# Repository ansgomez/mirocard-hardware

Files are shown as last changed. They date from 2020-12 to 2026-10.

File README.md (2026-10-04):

# MiroCard Hardware Files

Hardware design files for the MiroCard, a batteryless, light-powered BLE smart card
(TI CC2650 MCU, e-peas AEM10941 harvester, Epishine organic solar cell).

The current version, `MiroCard_V2.0/`, contains:

* `Datasheet_MiroCard_V2.pdf` – datasheet
* `Schematics_MiroCard_V2.pdf` – schematics
* `Altium_Files_MiroCard_V2/` – Altium project for the PCB design and production
  (schematics, PCB, libraries, Gerber/drill/pick-and-place outputs, BOM and STEP model)

Contact: [Andres Gomez](https://andresgomez.ch).

## Contributors

* Sinan Uyan (PCB layout)
* Andres Gomez

## MiroCard project

Project website: <https://ansgomez.github.io/mirocard-website/>

The MiroCard is a batteryless, light-powered BLE smart card, designed by Andres Gomez
(Miromico AG) and inspired by the
[Transient BLE Node](https://gitlab.ethz.ch/tec/public/employees/sigristl/transient_ble_node)
project developed at ETH Zurich. It was presented in:

> Andres Gomez. 2020. *Demo Abstract: On-Demand Communication with the Batteryless MiroCard.*
> In The 18th ACM Conference on Embedded Networked Sensor Systems (SenSys '20).
> [doi:10.1145/3384419.3430440](https://doi.org/10.1145/3384419.3430440)

Related repositories:

| Repository | Contents |
| --- | --- |
| **mirocard-hardware** (this repository) | Hardware: datasheet, schematics and Altium PCB project (MiroCard V2.0) |
| [mirocard-contiki-ng](https://github.com/ansgomez/mirocard-contiki-ng) | Firmware: Contiki-NG fork with the MiroCard platform and example applications |
| [miroreader-app](https://github.com/ansgomez/miroreader-app) | Android app to receive and display MiroCard beacons |
| [mirocard-scanner-python](https://github.com/ansgomez/mirocard-scanner-python) | Python scripts to scan for and decode MiroCard beacons (bluepy) and discover devices (gattlib) |
| [mirocard-scanner-mqtt](https://github.com/ansgomez/mirocard-scanner-mqtt) | Node.js bridge forwarding MiroCard beacons to an MQTT broker |
| [mirocard-scanner-influx](https://github.com/ansgomez/mirocard-scanner-influx) | Node.js bridge storing MiroCard beacons in InfluxDB |
| [mirocard-webid](https://github.com/ansgomez/mirocard-webid) | Web Bluetooth demo page for identification and sensor readout |
| [mirocard-postprocessing](https://github.com/ansgomez/mirocard-postprocessing) | Jupyter notebook to post-process RocketLogger power measurements |
| [mirocard-plotly](https://github.com/ansgomez/mirocard-plotly) | Plotly Dash web app visualizing a RocketLogger measurement |

## Copyright and License

The MiroCard and MiroReader app are designed by Andres Gomez, inspired by the
[Transient BLE Node](https://gitlab.ethz.ch/tec/public/employees/sigristl/transient_ble_node)
project developed at ETH Zurich. The Transient BLE Node project is released under the
Creative Commons Attribution 4.0 International License (CC BY 4.0); the Altium libraries
`MiroCard/TransientBLE.SCHLIB` and `MiroCard/TransientBLE.PcbLib` originate from that project.

The MiroCard hardware files are released under the BSD 3-Clause License, see [LICENSE](LICENSE).

Copyright: (c) 2020, Andres Gomez, Miromico AG

Copyright: (c) 2017-2020, ETH Zurich, Computer Engineering Group and Microelectronics Design Center.

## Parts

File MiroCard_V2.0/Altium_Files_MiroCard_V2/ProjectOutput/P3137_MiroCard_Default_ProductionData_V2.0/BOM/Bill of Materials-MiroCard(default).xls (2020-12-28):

 | Part List |  |  |  | P3137001-02
 | Project Number: |  |  |  | P3137 |  |  | Author Miromico: | AG
 | Project: |  |  |  | MiroCard.PrjPcb |  |  | Quantity: | 0 | Total quantity = Quantity + Prototypes
 | Variant: |  |  |  | default |  |  | Prototypes: | 1
 | Revision: |  |  |  | 2.0
 | Report Date: |  |  | 16.12.2020 | 14:37
 |  |  |  |  |  |  |  |  |  |  |  |  |  |  |  | Pricing
Pos. | PartType | Designator | Quantity | Needed Qty | Footprint | Description | Properties | Comment | Manufacturer | Manufacturer Part Number | Supplier 1 | Supplier Part Number 1 | #Column Name Error:' Supplier 2 | #Column Name Error:' Supplier Part Number 2 | Replaceable (with) | Supplier Currency 1 | Supplier Unit Price 1 | Supplier Subtotal 1 | #Column Name Error:' Supplier Currency 2 | #Column Name Error:' Supplier Unit Price 2 | #Column Name Error:' Supplier Subtotal 2
 | GRM155R61C104KA88D | C100, C101, C102, C103, C106, C107, C115, C118, C206, C401 | 10 | 10 | CAPC0402(1005)60_L | 0.1µF ±10% 16V Ceramic Capacitor X5R 0402 (1005 Metric) |  | GRM155R61C104KA88D | Murata Electronics | GRM155R61C104KA88D | Digi-Key | 490-5415-1-ND
 | GRJ155R60J106ME11D | C104, C105, C300, C301, C302, C303, C304, C406 | 8 | 8 | CAPC0402(1005)60_L | 10µF ±20% 6.3V Ceramic Capacitor X5R 0402 (1005 Metric) |  | GRJ155R60J106ME11D | Murata Electronics | GRJ155R60J106ME11D | Digi-Key | 490-13211-1-ND
 | CAP 6.8pF 10V 0402(1005) | C108 | 1 | 1 | CAPC0402(1005)60_L | CAP 6.8pF 10V ±5% 0402 (1005 Metric) Thickness 0.6mm SMD |  | CAP 6.8pF 10V 0402(1005)
 | GRM1555C1H1R0BA01D | C109, C112, C113 | 3 | 3 | CAPC0402(1005)60_L | 1pF ±0.1pF 50V Ceramic Capacitor C0G, NP0 0402 (1005 Metric) |  | GRM1555C1H1R0BA01D | Murata Electronics | GRM1555C1H1R0BA01D | Digi-Key | 490-6206-1-ND
 | CAP 12pF 10V 0402(1005) | C110 | 1 | 1 | CAPC0402(1005)60_L | CAP 12pF 10V ±2% 0402 (1005 Metric) Thickness 0.6mm SMD |  | CAP 12pF 10V 0402(1005)
 | GRM1555C1H1R8BA01D | C111 | 1 | 1 | CAPC0402(1005)60_L | 1.8pF ±0.1pF 50V Ceramic Capacitor C0G, NP0 0402 (1005 Metric) |  | GRM1555C1H1R8BA01D | Murata Electronics | GRM1555C1H1R8BA01D | Digi-Key | 490-6215-1-ND
 | GRM155R70J105KA12J | C114, C207 | 2 | 2 | CAPC0402(1005)60_L | 1µF ±10% 6.3V Ceramic Capacitor X7R 0402 (1005 Metric) |  | GRM155R70J105KA12J | Murata Electronics | GRM155R70J105KA12J | Digi-Key | 490-13339-1-ND
 | GRM1555C1H120JA01D | C116, C117 | 2 | 2 | CAPC0402(1005)60_L | 12pF ±5% 50V Ceramic Capacitor C0G, NP0 0402 (1005 Metric) |  | GRM1555C1H120JA01D | Murata Electronics | GRM1555C1H120JA01D | Digi-Key | 490-5924-1-ND
 | CAP 47uF 6.3V 0805(2012) | C204, C205 | 2 | 2 | CAPC0805(2012)95_L | CAP 47uF 6.3V ±20% 0805 (2012 Metric) Thickness 0.95mm SMD |  | CAP 47uF 6.3V 0805(2012)
 | GRM155R71E104KE14J | C400, C405 | 2 | 2 | CAPC0402(1005)60_L | 0.1µF ±10% 25V Ceramic Capacitor X7R 0402 (1005 Metric) |  | GRM155R71E104KE14J | Murata Electronics | GRM155R71E104KE14J | Digi-Key | 490-14603-1-ND
 | APTF1616LSEEZGKQBKC | D100 | 1 | 1 | APTF1616LSEEZGKQBKC | HELI Colour; 1.6X1.6MM LOW CURRENT RGB SMD LED | Red, Green, Blue (RGB) 621nm Red, 525nm Green, 465nm Blue LED Indication - Discrete 1.8V Red, 2.7V Green, 2.7V Blue 0606 (1616 Metric) | APTF1616LSEEZGKQBKC | Kingbright | APTF1616LSEEZGKQBKC | Digi-Key | 754-1972-1-ND
 | BLM18HE152SN1D | FB100 | 1 | 1 | MURA-BLM18-RF-H4-CHIP-2_V | Chip Ferrite Bead for GHz Band High-speed Signal Lines, 1500 Ohm, 500 mA, -55 to 125 degC, 1.6 x 0.8 x 0.95 mm SMD, Tape and Reel |  | BLM18HE152SN1D | Murata
 | CKS2125100M-T | L100, L300 | 2 | 2 | INDC0805(2012)X11_L | FIXED IND 10UH 110MA 520 MOHM |  | CKS2125100M-T
 | LQG15HS2N4S02D | L101, L102, L103, L104 | 4 | 4 | INDC1005X55X25LL05T10_A | Chip Inductor, 2.4 nH, +/- 0.3 nH, 300 mA, -55 to 125 degC, 0402 (1005 Metric), RoHS, Tape and Reel |  | LQG15HS2N4S02D | MurataElectronics
 | MLZ1608M100WT000 | L301 | 1 | 1 | FP-MLZ1608-MFG | FIXED IND 10UH 250MA 1.05 OHM |  | MLZ1608M100WT000 | TDK | MLZ1608M100WT000
 | RMCF0402FT300R | R102, R103, R104 | 3 | 3 | RESC0402(1005)_L | 300 Ohms ±1% 0,063W, 1/16W Chipwiderstand 0402 (1005 metrisch) AutomobilzulassungAEC-Q200 Dickschicht |  | RMCF0402FT300R | Stackpole Electronics Inc | RMCF0402FT300R | Digi-Key | RMCF0402FT300RCT-ND
 | RMCF0402FT100K | R105, R108, R201, R207 | 4 | 4 | RESC0402(1005)_L | 100 kOhms ±1% 0,063W, 1/16W Chipwiderstand 0402 (1005 metrisch) AutomobilzulassungAEC-Q200 Dickschicht |  | RMCF0402FT100K | Stackpole Electronics Inc | RMCF0402FT100K | Digi-Key | RMCF0402FT100KCT-ND
 | RMCF0402FT1M00 | R106, R107 | 2 | 2 | RESC0402(1005)_L | 1 MOhms ±1% 0,063W, 1/16W Chipwiderstand 0402 (1005 metrisch) AutomobilzulassungAEC-Q200 Dickschicht |  | RMCF0402FT1M00 | Stackpole Electronics Inc | RMCF0402FT1M00 | Digi-Key | RMCF0402FT1M00CT-ND
 | PFR05S-153-FNH | R200 | 1 | 1 | RESC0402(1005)_L | 15 kOhms ±1% 0.063W, 1/16W Chip Resistor 0402 (1005 Metric) Thick Film |  | PFR05S-153-FNH | Delta Electronics/Cyntec | PFR05S-153-FNH | Digi-Key | 2037-PFR05S-153-FNHCT-ND
 | CRCW04023M16FKED | R202 | 1 | 1 | RESC0402(1005)_L | 3.16 MOhms ±1% 0.063W, 1/16W Chip Resistor 0402 (1005 Metric) Automotive AEC-Q200 Thick Film |  | CRCW04023M16FKED | Vishay Dale | CRCW04023M16FKED | Digi-Key | 541-3.16MLCT-ND
 | RMCF0603ZT0R00 | R204 | 1 | 1 | RESC0603(1608)_L | 0 Ohms Jumper 0.1W, 1/10W Chip Resistor 0603 (1608 Metric) Automotive AEC-Q200 Thick Film |  | RMCF0603ZT0R00 | Stackpole Electronics Inc | RMCF0603ZT0R00 | Digi-Key | RMCF0603ZT0R00CT-ND
 | RMCF0402FT1M18 | R205 | 1 | 1 | RESC0402(1005)_L | 1.18 MOhms ±1% 0.063W, 1/16W Chip Resistor 0402 (1005 Metric) Automotive AEC-Q200 Thick Film |  | RMCF0402FT1M18 | Stackpole Electronics Inc | RMCF0402FT1M18 | Digi-Key | RMCF0402FT1M18CT-ND
 | RMCF0402FT2M40 | R206 | 1 | 1 | RESC0402(1005)_L | 2.4 MOhms ±1% 0.063W, 1/16W Chip Resistor 0402 (1005 Metric) Automotive AEC-Q200 Thick Film |  | RMCF0402FT2M40 | Stackpole Electronics Inc | RMCF0402FT2M40 | Digi-Key | RMCF0402FT2M40CT-ND
 | RMCF0402ZT0R00 | R301, R307, R309, R311, R312, R318 | 6 | 6 | RESC0402(1005)_L | 0 Ohms Jumper 0.063W, 1/16W Chip Resistor 0402 (1005 Metric) Automotive AEC-Q200 Thick Film |  | RMCF0402ZT0R00 | Stackpole Electronics Inc | RMCF0402ZT0R00 | Digi-Key | RMCF0402ZT0R00CT-ND
 | CRCW04025M49FKED | R303 | 1 | 1 | RESC0402(1005)_L | 5.49 MOhms ±1% 0.063W, 1/16W Chip Resistor 0402 (1005 Metric) Automotive AEC-Q200 Thick Film |  | CRCW04025M49FKED | Vishay Dale | CRCW04025M49FKED | Digi-Key | 541-5.49MLCT-ND
 | CRCW04024M42FKED | R304 | 1 | 1 | RESC0402(1005)_L | 4.42 MOhms ±1% 0.063W, 1/16W Chip Resistor 0402 (1005 Metric) Automotive AEC-Q200 Thick Film |  | CRCW04024M42FKED | Vishay Dale | CRCW04024M42FKED | Digi-Key | 541-4.42MLCT-ND
 | AC0402FR-0710KL | R400, R401, R402, R403, R404 | 5 | 5 | RESC0201(0603)_L | 10 kOhms ±1% 0.063W, 1/16W Chip Resistor 0402 (1005 Metric) Automotive AEC-Q200, Moisture Resistant Thick Film |  | AC0402FR-0710KL | Yageo | AC0402FR-0710KL | Digi-Key | YAG3436CT-ND
 | KMT021NGJLHS | SW100, SW101 | 2 | 2 | KMT021NGJLHS-Footprint-1 | Sensorschalter Ultra-LW Tact SW SMT SPNOFa 1.6N HF |  | KMT021NGJLHS | C&K | KMT021NGJLHS | Mouser | 611-KMT021NGJLHS
 | LEH3_50x30_6_10 | U1 | 1 | 1 | 50x30 Flat 6 Cell - Gen 2-Footprint-1 | Solar Cell 50x30 Flat 6 Cell |  | LEH3_50x30_6_10 | Epishine | LEH3_50x30_6_10 | Epishine | LEH3_50x30_6_10
 | CC2650F128RGZR | U100 | 1 | 1 | RGZ0048A_V | CC2650 SimpleLink(TM) Multistandard Wireless MCU, 1.8 to 3.8 V, -40 to 85 degC, 48-Pin VFQFN, Green (RoHS & no Sb/Br), Tape and Reel |  | CC2650F128RGZR | Texas Instruments
 | ADG659YCPZ-REEL7 | U200 | 1 | 1 | CP-16-4_L | 3 V / 5 V / +/-5 V CMOS 4-Channel Analog Multiplexer, -40 to 85 degC, 16-pin QFN (CP-16-4), Reel |  | ADG659YCPZ-REEL7 | Analog Devices
 | LTC1540IDD#TRPBF | U201 | 1 | 1 | LT-DD8_V | Nanopower Comparator with Reference, 1 Channel, 2 to 11 V, -40 to +85 degC, 8-pin Plastic DFN (DD8), Tape and Reel |  | LTC1540IDD#TRPBF | Linear Technology
 | TLV840XXDH43DBVR | U202 | 1 | 1 | SOT23-5 SOT-23-5 | Low-voltage supervisor with adjustable-reset time delay and manual reset |  | TLV840XXDH43DBVR | Texas Instruments | TLV840XXDH43DBVR | Texas Instruments | TLV840XXDH43DBVR
 | AEM10941 | U300 | 1 | 1 | QFN50P500X500X85_HS-29N | Highly-efficient, regulated dual-output, ambient energy manager |  | AEM10941 | e-peas | AEM10941 | e-peas | AEM10941
 | SHT31-DIS-B | U400 | 1 | 1 | 8 - Pin DFN 2.5 x 2.5 mm x 0.9 mm | SENSIRION SHT31-DIS-B Humidity Sensor, 2 %, 3.3 V, 0% to 100% Relative Humidity, TDFN, 8 Pins, 8 s |  | SHT31-DIS-B | Sensirion | SHT31-DIS-B | Digi-Key | 1649-1011-1-ND
 | DRV5032FBDBZR | U402 | 1 | 1 | SOT23-3 | HAL SENSOR, ULTRA-LOW POWER, 1.65V TO 5.5V |  | DRV5032FBDBZR | Texas Instruments | DRV5032FBDBZR | Digikey | 296-47323-1-ND
 | LIS3DHTR | U405 | 1 | 1 | FP-LGA-16-7983231-MFG | ACCEL 2-16G I2C/SPI 16LGA |  | LIS3DHTR
 | TSX-3225 24.0000MF15X-AC3 | X100 | 1 | 1 | EPSON-TSX-3225_V | MHz Range Crystal, 24 MHz, -40 to 85 degC, 4-Pin SMD, RoHS, Tape and Reel |  | TSX-3225 24.0000MF15X-AC3 | Epson
 | ABS07-120-32.768KHZ-T | Y100 | 1 | 1 | ABRA-ABS07_A_V | Tuning Fork Crystal, 32.768 KHz, +/- 20 ppm, -40 to 85 degC, 2-Pin SMD, RoHS, Tape and Reel |  | ABS07-120-32.768KHZ-T | Abracon

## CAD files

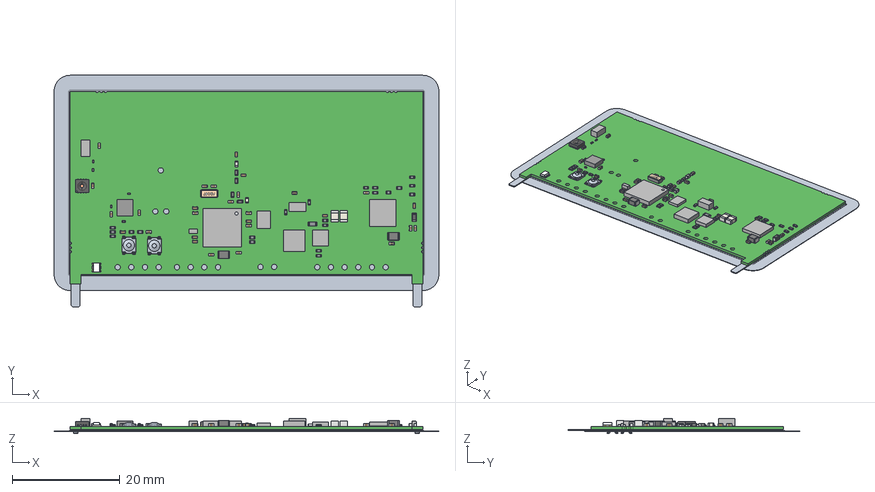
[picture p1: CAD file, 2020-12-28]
MiroCard_V2.0/Altium_Files_MiroCard_V2/ProjectOutput/P3137_MiroCard_Default_ProductionData_V2.0/P3137_MiroCard_Default_STEP_V2.0.step
71.5 x 43.0 x 2.77 mm
LEH3_50x30_6_10_B
Metal_Contact x 2
R0201 x 20
User_Library-cap_0402 x 28
Open_CASCADE_STEP_translator_6.8_7.1.1 x 2
Open_CASCADE_STEP_translator_6.8_7.1.2 x 2
Open_CASCADE_STEP_translator_6.8_7.2.1 x 2
ABS07
Extruded x 22
User_Library-SHT3x_BODY
User_Library-SHT3x_PADS
KMT022NGJLHS x 2
R0402 x 84
R0603 x 4
center
poles
pole
Open_CASCADE_STEP_translator_6.8_11.1.1 x 4
Open_CASCADE_STEP_translator_6.8_11.1.2 x 4
Open_CASCADE_STEP_translator_6.8_11.2.1 x 4
APTF1616

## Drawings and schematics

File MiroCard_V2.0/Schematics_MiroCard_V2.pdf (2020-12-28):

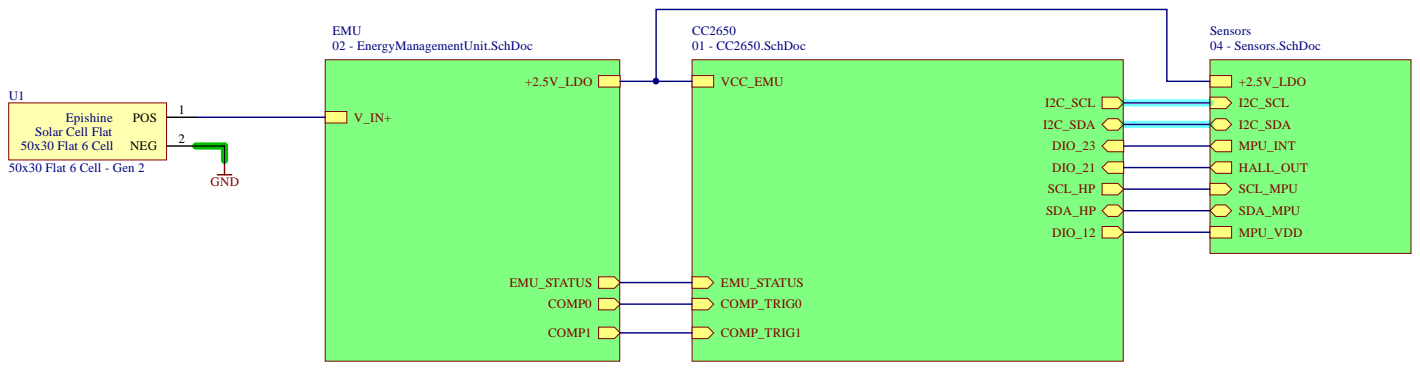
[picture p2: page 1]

Schem a T i t le: O ver view | Autho r : A G

P r o jec t : P3137 | PCB -N o.: P 3 1 3 7 0 0 1 -0 2 | Co -Autho r : S
PCB N a me: M i r oCa r d | V a r i ant : def aul t | UDSAG Rev iewer :

Rev i s i on: | Cus t o mer : M i r o m i c o | Chec ked b y :

D a te: 07.12.2020 | T i me: 11:14:43 | Sheet : o f | D o c N a me: 00 - O ver v iew.S chD o c | A

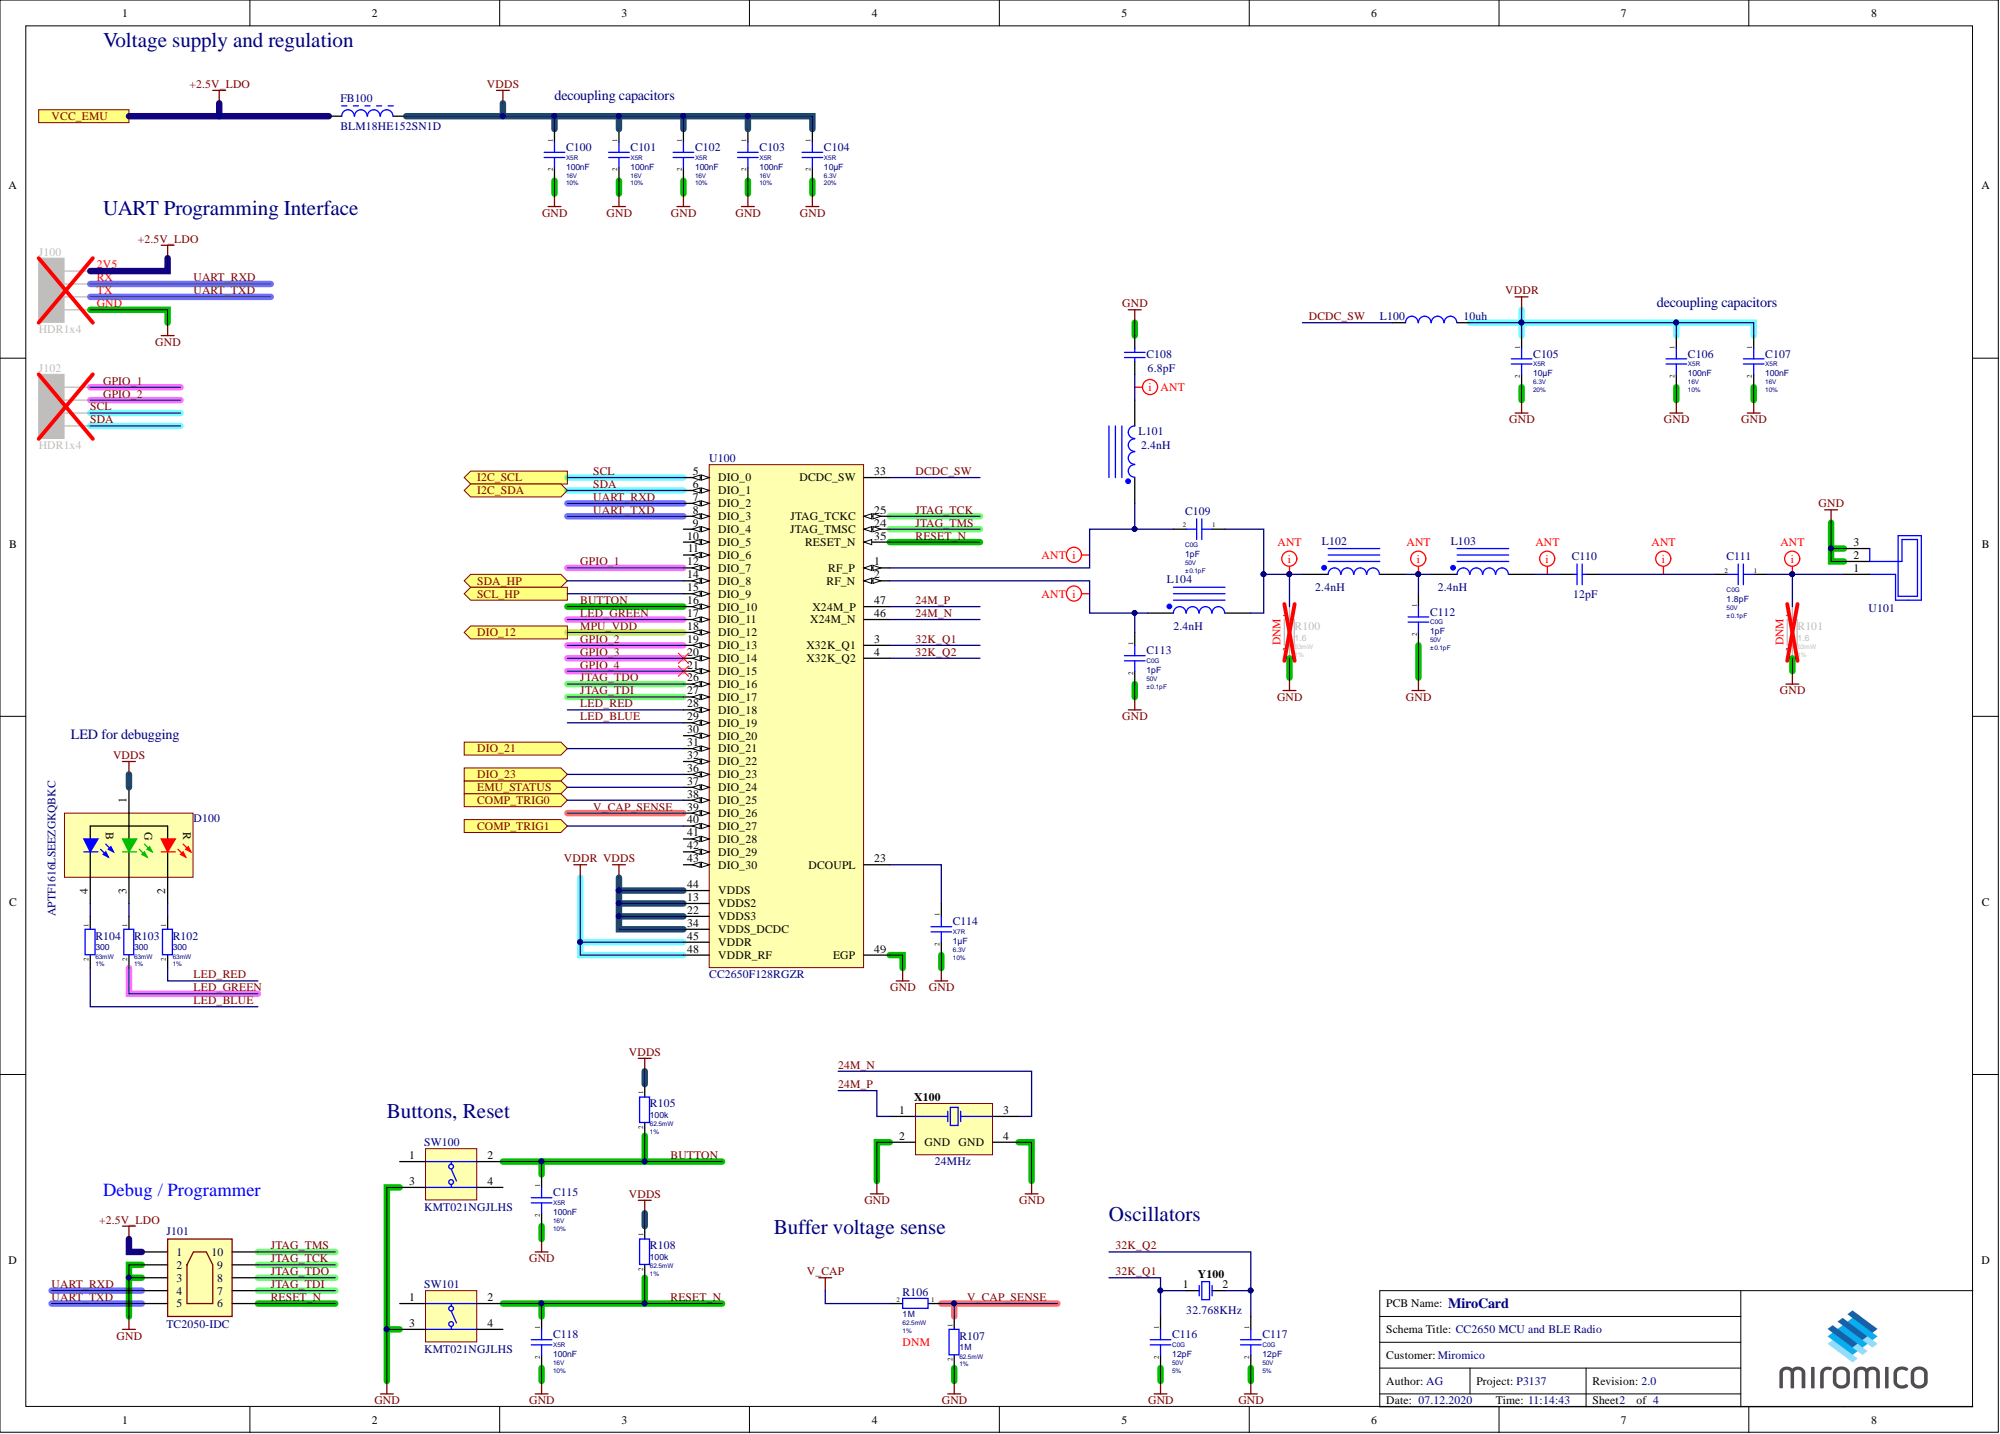
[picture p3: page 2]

Voltage supply and regulation

DIO_5 10 | RESET_N ANT i

VDDS2 13
VDDS3 22

CC2650 MCU and BLE Radio

Author: AG | Project: P3137 | Revision:
Date: Time: | | Sheet of

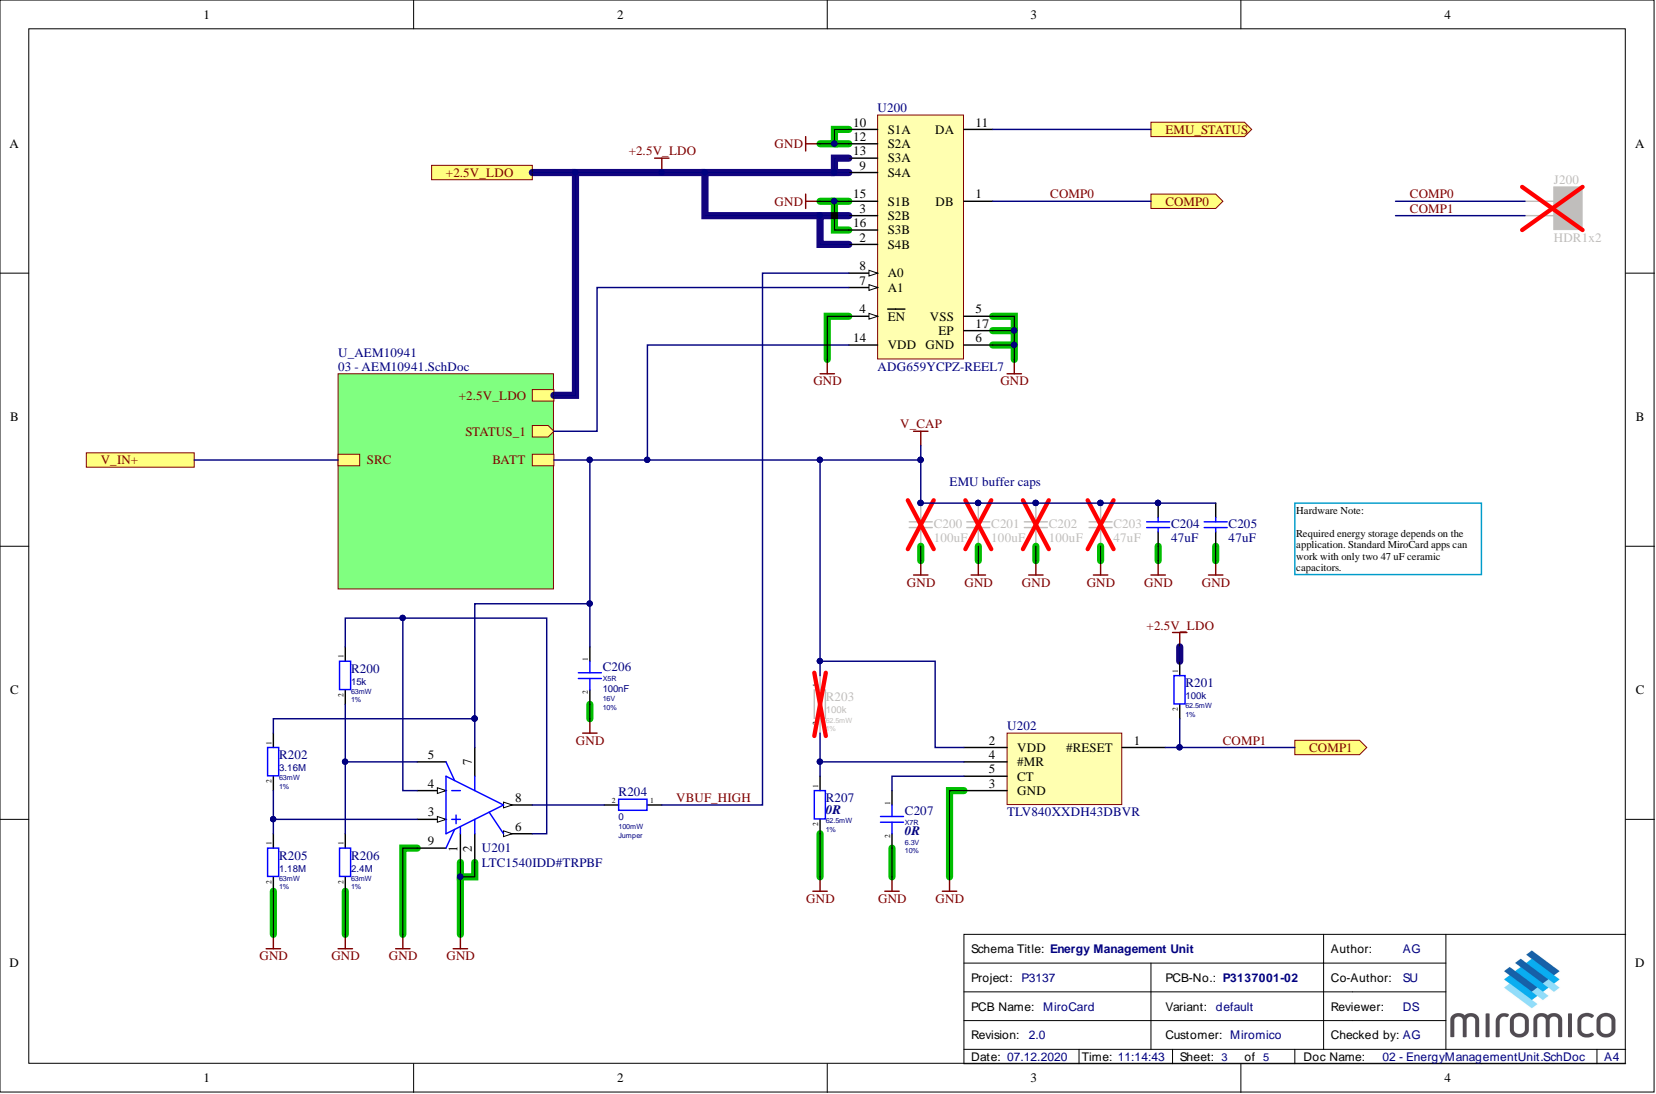
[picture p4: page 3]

Required energy storage depends on the
application. Standard MiroCard apps can
work with only two 47 uF ceramic
capacitors.

GND 3

Schema Title: Energy Management Unit | Author: AG

Project: P3137 | PCB-No.: P3137001-02 | Co-Author: SU

PCB Name: MiroCard | Variant: default | Reviewer: DS

Checked by: AG

Time: | Sheet: of | Doc Name: 02 - EnergyManagementUnit.SchDoc | A4

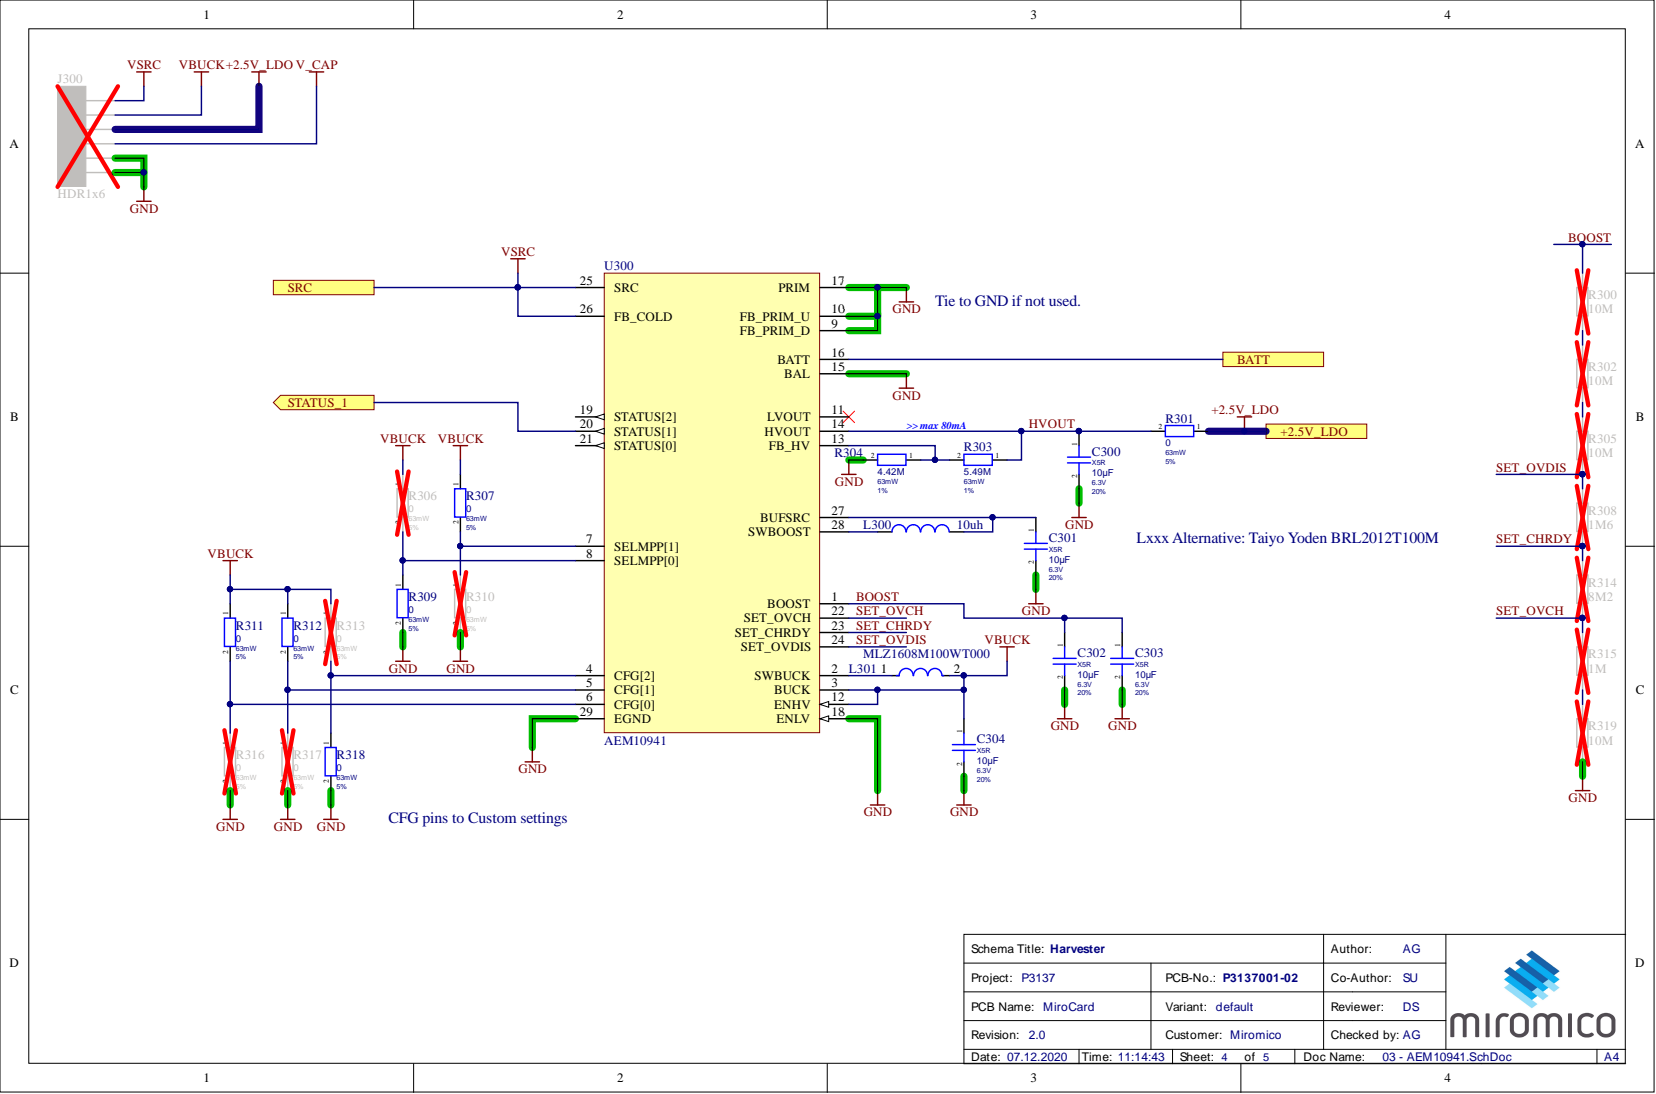
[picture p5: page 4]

6 | 1 2
2 9 | 1 8

Schem a T i t le: Har vester | Autho r : A G

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

D a te: | T i me: | Sheet : o f | D o c N a me: 03 - A E M10941.S chD o c | A

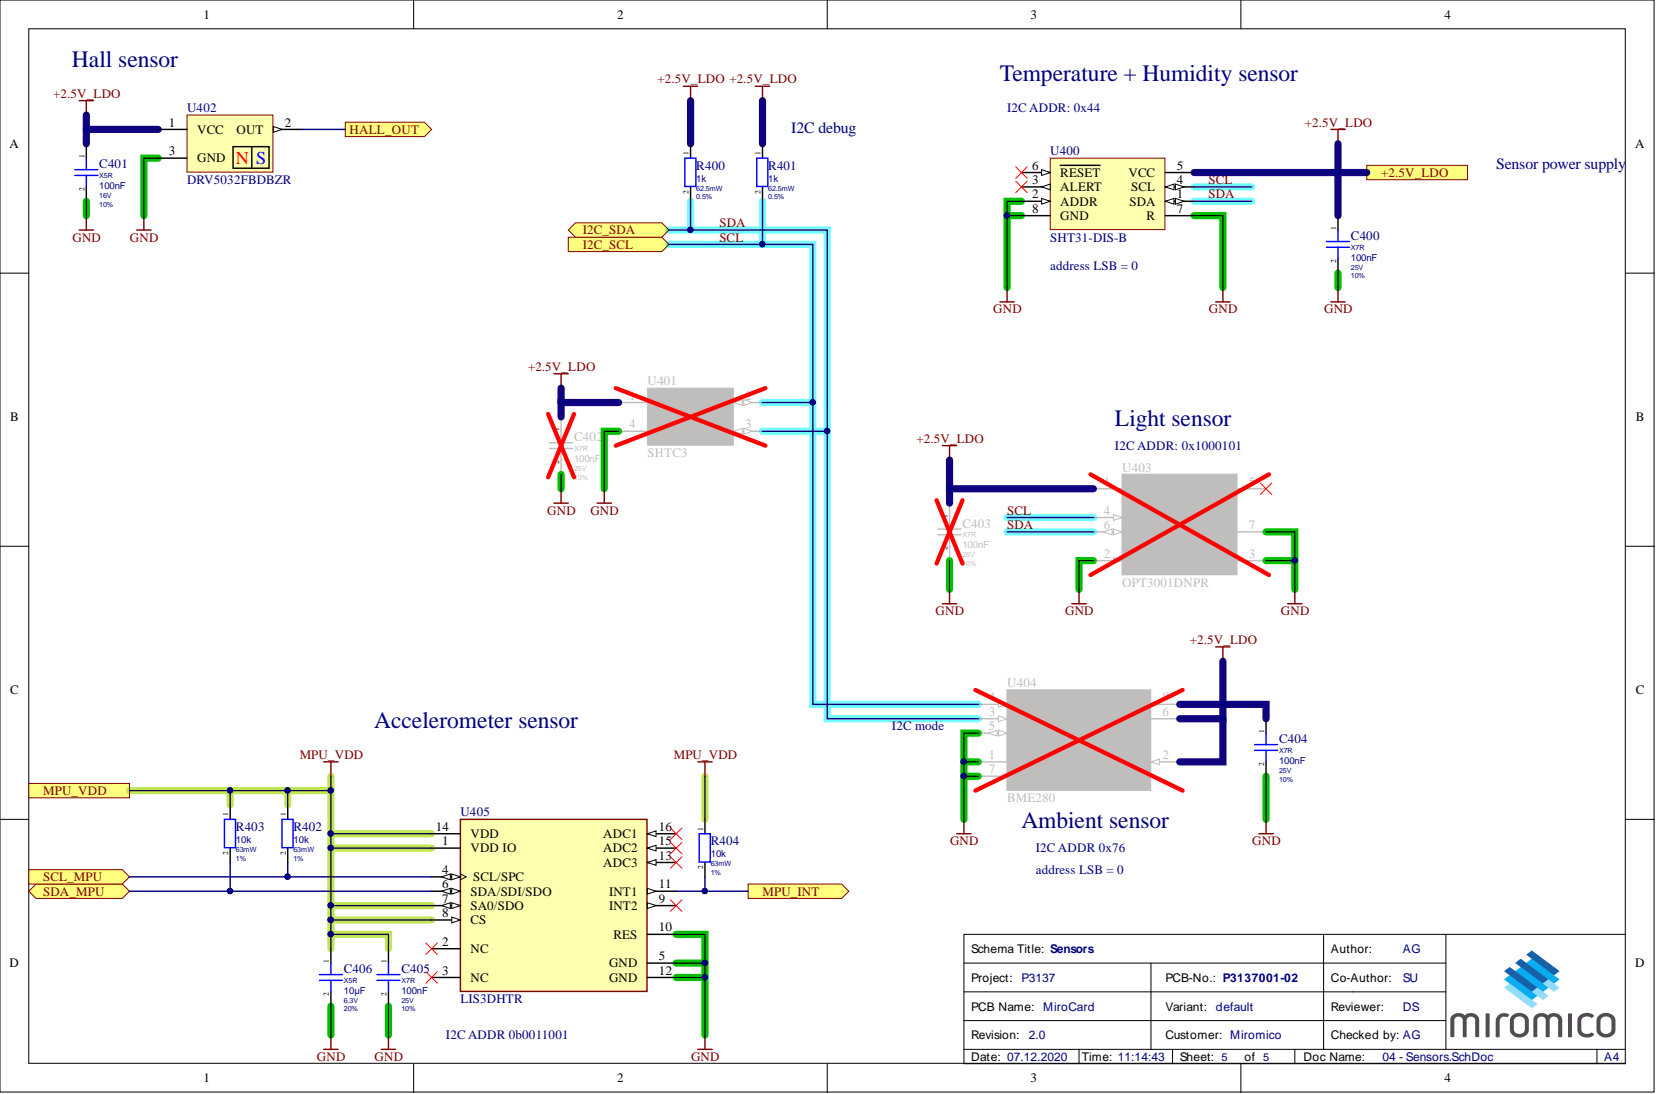
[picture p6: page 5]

SCL/SPC 4

SA0/SDO 7

Project: P3137 | PCB-No.: P3137001-02 | Co-Author: SU

PCB Name: MiroCard | Variant: default | Reviewer: DS

Checked by: AG

Time: | Sheet: of | Doc Name: 04 - Sensors.SchDoc | A4

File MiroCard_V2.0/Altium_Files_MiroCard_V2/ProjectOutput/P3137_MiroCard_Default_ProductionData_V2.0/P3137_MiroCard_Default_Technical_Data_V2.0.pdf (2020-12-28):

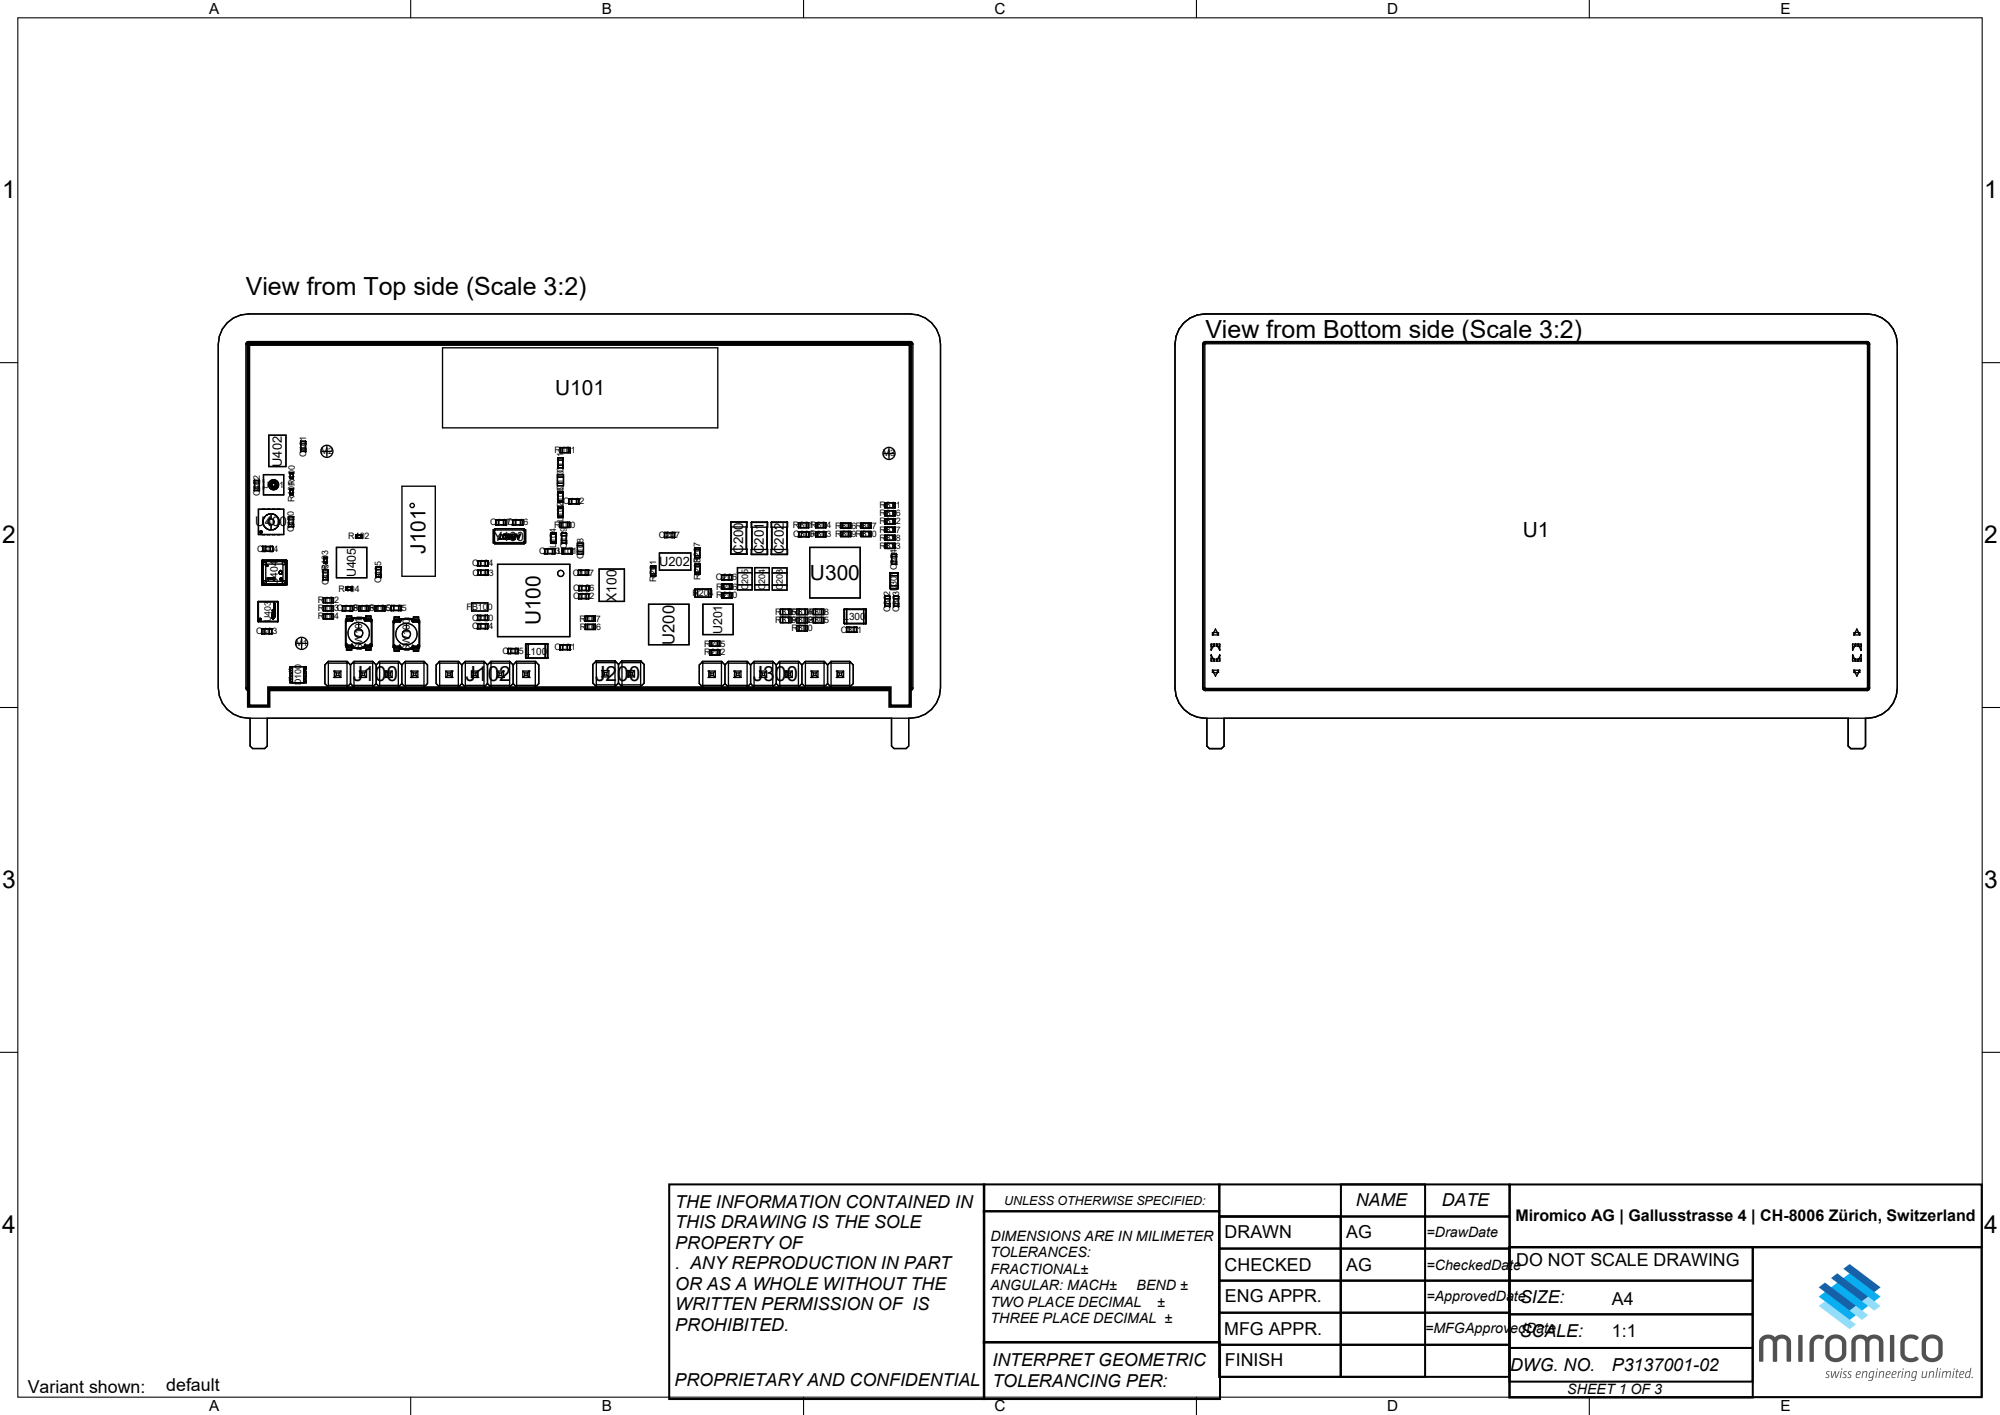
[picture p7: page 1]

View from Top side (Scale 3:2)

View from Bottom side (Scale 3:2)

THE INFORMATION CONTAINED IN THIS DRAWING IS THE SOLE PROPERTY OF . ANY REPRODUCTION IN PART OR AS A WHOLE WITHOUT THE WRITTEN PERMISSION OF IS PROHIBITED. PROPRIETARY AND CONFIDENTIAL | UNLESS OTHERWISE SPECIFIED: | | NAME | DATE | Miromico AG | Gallusstrasse 4 | CH-8006 Zürich, Switzerland

DIMENSIONS ARE IN MILIMETER TOLERANCES: FRACTIONAL± ANGULAR: MACH± BEND ± TWO PLACE DECIMAL ± THREE PLACE DECIMAL ± | DRAWN | AG | =DrawDate

CHECKED | AG | =CheckedDate | DO NOT SCALE DRAWING
ENG APPR. | | =ApprovedDate | SIZE: A4
MFG APPR. | | =MFGApprovedDate | SCALE:

TOLERANCING PER: | FINISH | | | DWG. NO. P3137001-02

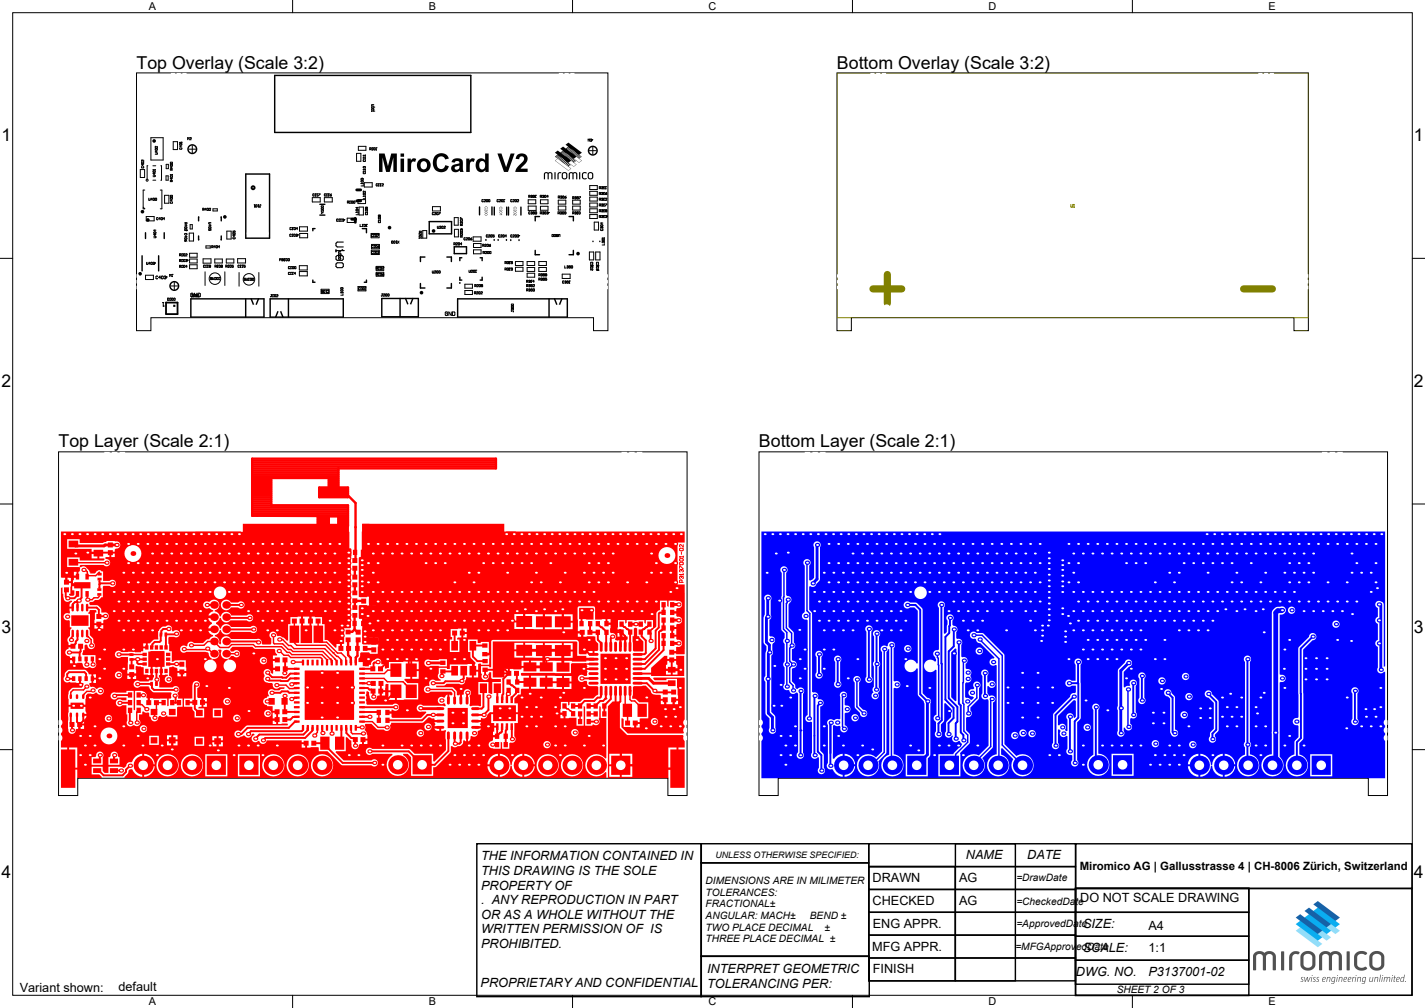
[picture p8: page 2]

THE INFORMATION CONTAINED IN THIS DRAWING IS THE SOLE PROPERTY OF . ANY REPRODUCTION IN PART OR AS A WHOLE WITHOUT THE | UNLESS OTHERWISE SPECIFIED: | | NAME | DATE | Miromico AG | Gallusstrasse 4 | CH-8006 Zürich, Switzerland

DIMENSIONS ARE IN MILIMETER TOLERANCES: FRACTIONAL± ANGULAR: MACH± BEND ± | DRAWN | AG | =DrawDate

CHECKED | AG | =CheckedDate | DO NOT SCALE DRAWING
ENG APPR. | | | SIZE: A4

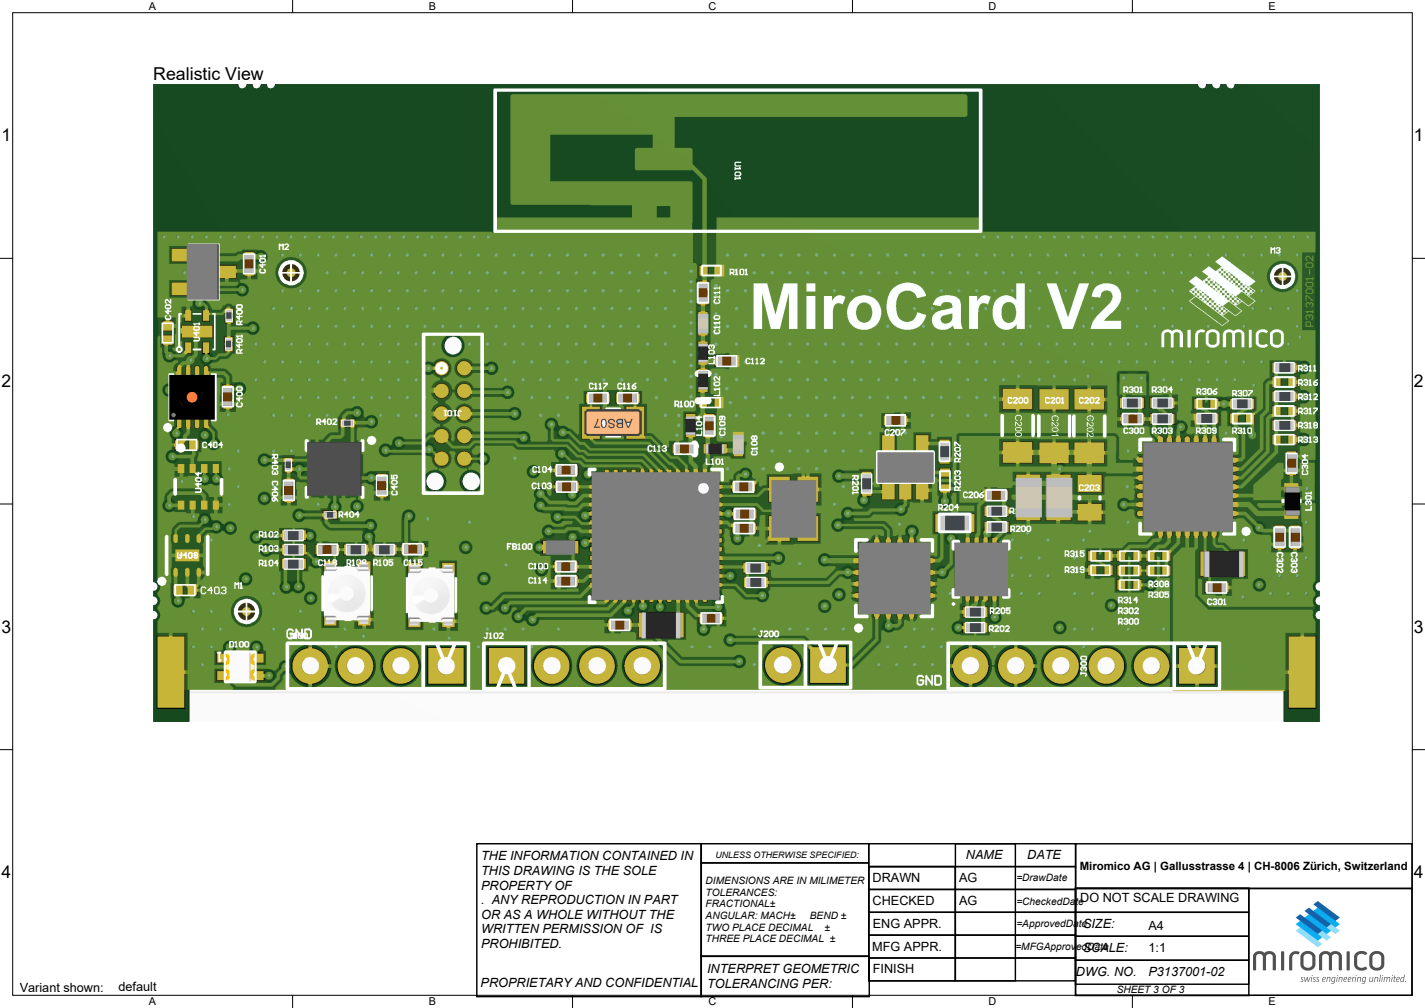
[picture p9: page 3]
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

DIMENSIONS ARE IN MILIMETER TOLERANCES: FRACTIONAL± ANGULAR: MACH± BEND ± | DRAWN | AG | =DrawDate

CHECKED | AG | =CheckedDate | DO NOT SCALE DRAWING
ENG APPR. | | | SIZE: A4

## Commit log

2020-12-28 Adds altium files and documentation
    [00 - Overview.SchDoc, 01 - CC2650.SchDoc, 02 - EnergyManagementUnit.SchDoc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]
2026-10-04 fix(license): switch hardware files to BSD-3-Clause
    Replace the MIT license (which misspelled the holder as "MiroMico AG")
    with BSD-3-Clause held by Andres Gomez, Miromico AG, update the README
    license note, and credit Sinan Uyan for the PCB layout.
    Claude-Session: https://claude.ai/code/session_015Mvmd85KZNecaKHogBUo3c
2026-10-04 docs(readme): describe hardware contents, link MiroCard project repos
    Rewrite the README with the board's key components, the SenSys '20 demo
    citation, a table of related MiroCard repositories, ETH Zurich credit for
    the Transient BLE Node libraries, and a current contact link replacing the
    defunct mirocard.swiss addresses.
    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
